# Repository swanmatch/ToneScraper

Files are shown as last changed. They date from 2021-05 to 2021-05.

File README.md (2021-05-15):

# ToneScraper

## 概要

[せきごんさん](https://github.com/sekigon-gonnoc)の[mtch6102評価基板](https://github.com/sekigon-gonnoc/mtch6102_breakout)を参考に、タッチパッドとロータリーエンコーダーを3機搭載した4キーマイクロパッド。

ロータリーエンコーダーは単色の光るエンコーダーかプッシュスイッチ付きのもののどちらか選んで実装できます。

## 部品リスト

| 品目 | 数量 | 備考 |
| :--- | ---: | :--- |
| PCB |  1枚 |  |
| トッププレート |  1枚 |  |
| ボトムプレート |  1枚 |  |
| ProMicro |  1個 |  |
| コンスルー |  2本 |  |
| LED(SK6812mini) |  4個 |  |
| MTCH6102 |  1個 |  |
| レベル変換基板 |  1個 | https://nogikes.booth.pm/items/2008258 |
| 4pinピンヘッダー |  1個 |  |
| ハーフピッチ5pinピンヘッダー |  1個 |  |
| アナログ5mm砲丸LED |  1個 |  |
| 220Ω抵抗 |  1個 |  |
| M2L8丸スペーサ |  4本 |  |
| M2L7六角スペーサ(オスメス) |  6本 |  |
| M2L4ネジ |  8本 |  |
| アングルタクトスイッチ |  1個 |  |
| ゴム足 |  4個 |  |
| KailhChocスイッチ |  4個 |  |
| 1Uキーキャップ |  4個 |  |
| USBケーブル |  1本 |  |
| TRRS JACK |  2個 | パームレスト for SilverbulletRequiemを光らせる場合 |
| TRRSまたはTRSケーブル |  2本 | パームレスト for SilverbulletRequiemを光らせる場合必|
| 圧電サウンダ(PKLCS1212) |  1個 | 圧電サウンダを実装する場合 |
| ダイオード |  1個 | 圧電サウンダを実装する場合 |
| 1KΩ抵抗 | 1個 | 圧電サウンダを実装する場合 |
| 光るロータリーエンコーダー | 3個 | [赤](https://akizukidenshi.com/catalog/g/gP-05762/) [青](https://akizukidenshi.com/catalog/g/gP-05768/) [黄緑](https://akizukidenshi.com/catalog/g/gP-05767/) |
| 100Ω抵抗 |  3個 | 光るロータリーエンコーダーを実装する場合 |
| 通常ロータリーエンコーダー  |  3個 |  |

## 組み立て手順

### LEDの実装

LEDをはんだ付けします。  
欠けている足が右上の三角のシルクに対応します。

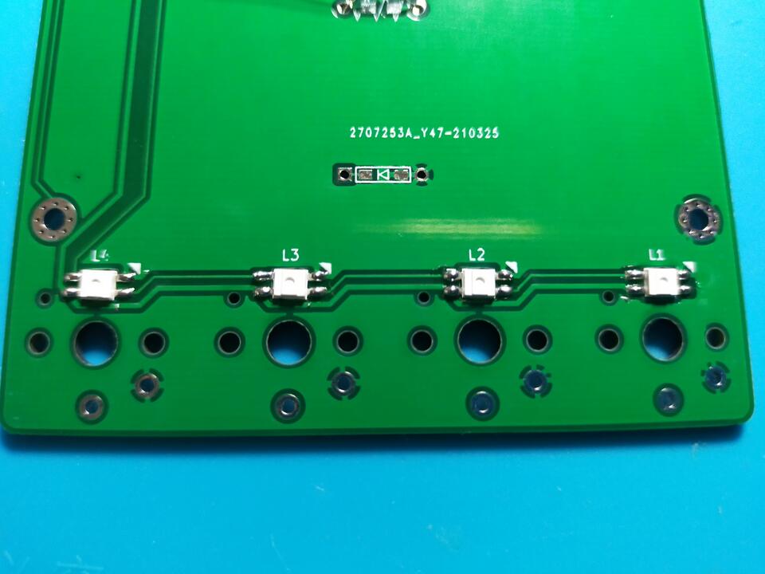
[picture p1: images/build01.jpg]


### アナログLED・抵抗の実装

アナログLEDの横の抵抗とLEDを実はんだ付けします。

LEDは数ミリ浮かせた状態で実装して、トッププレートを付けたときにはみ出るとかっこいいです。

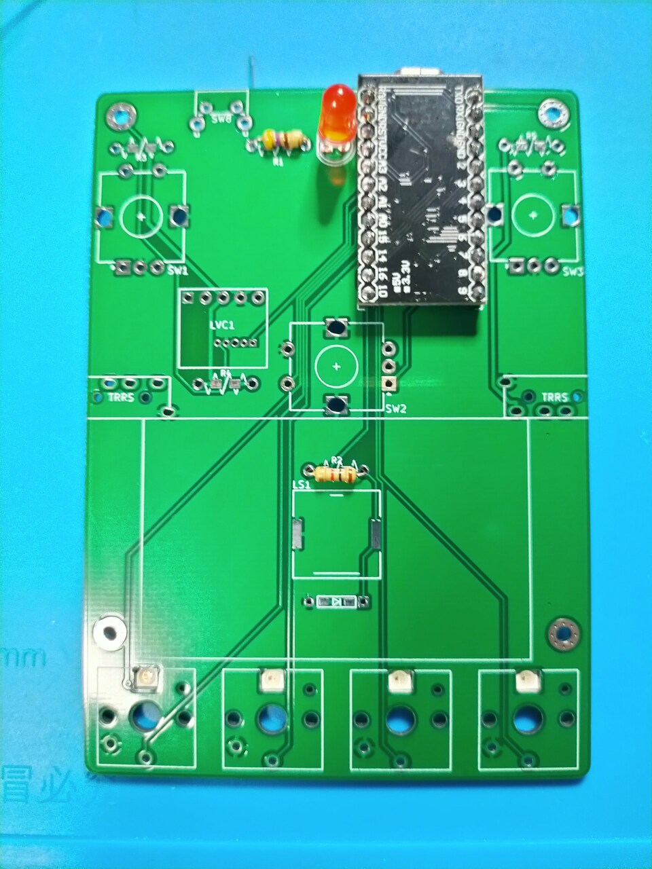
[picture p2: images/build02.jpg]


圧電サウンダを使う場合、ダイオードと1kΩ抵抗、圧電サウンダを、
光るエンコーダーを使う場合、その他の抵抗のフットプリントに100Ω抵抗を実装します。

＊) 圧電サウンダの実装を忘れて写真を撮りました…！

### リセットスイッチ、TRRSジャックの実装

TRRSジャックと、タクトスイッチを実装します。

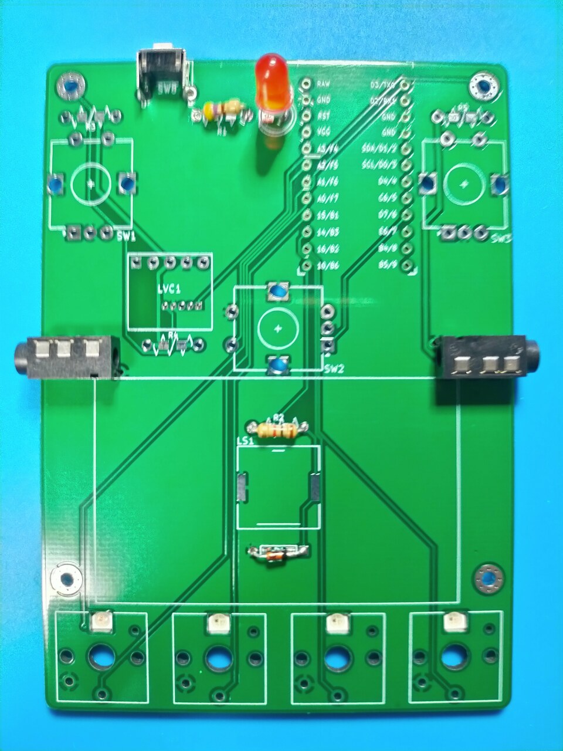
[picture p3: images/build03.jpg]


### レベル変換基板用のピンヘッダの実装

レベル変換基板用のピンヘッダをはんだ付けします。

標準ピッチ基板は表(スイッチ面)から見て一番右側は使っていないので左寄せにします。

ピンヘッダを傾けてはんだ付けしてしまうと変換基板がハマらないので、
変換基板を載せた状態でマスキングテープで固定して、裏からはんだ付けします。

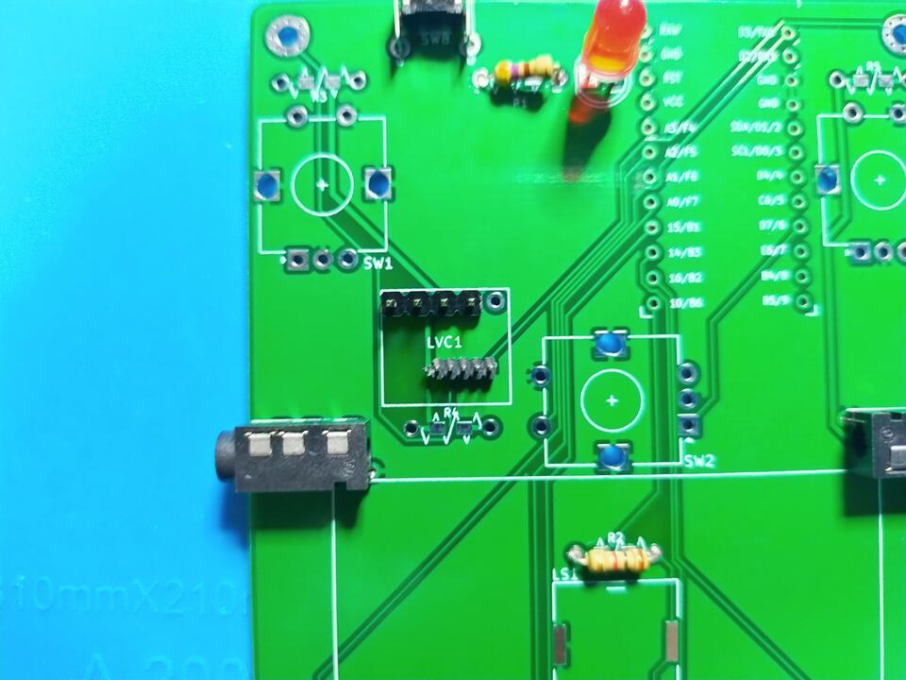
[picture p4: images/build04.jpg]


続いてレベル変換基板をはんだ付けします。

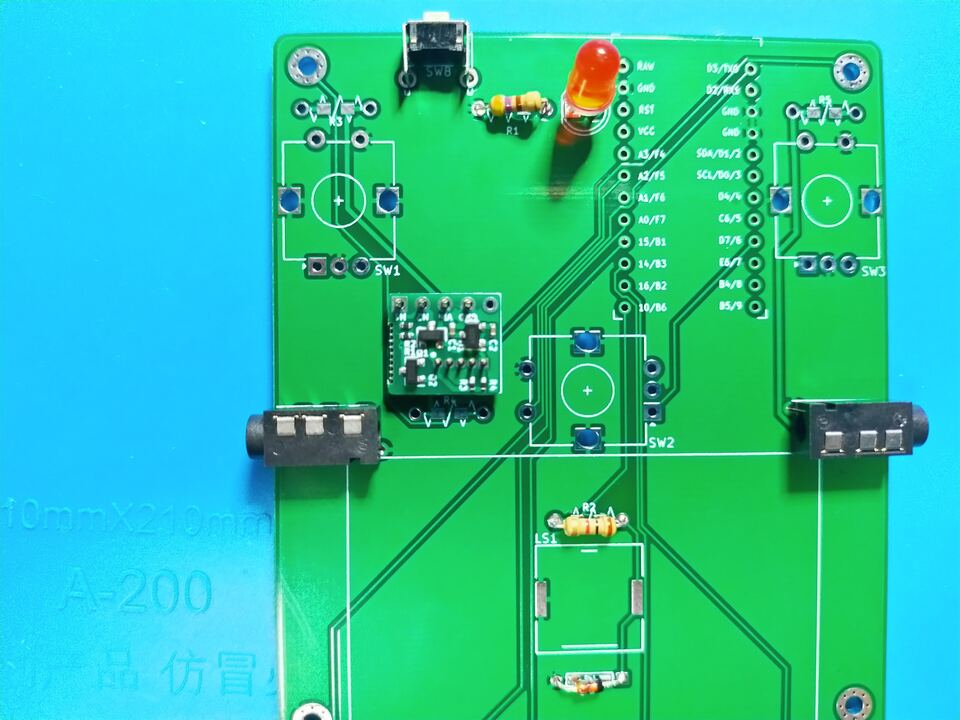
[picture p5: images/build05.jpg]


### Chocスイッチとロータリーエンコーダーの実装

ロータリーエンコーダーとChocスイッチをはんだ付けします。

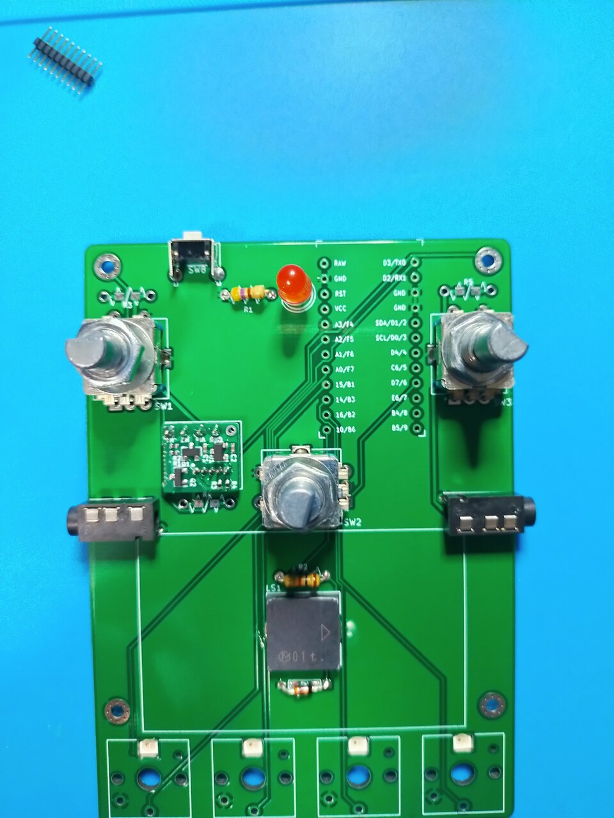
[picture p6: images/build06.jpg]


＊) chocの実装を忘れて写真を撮りました…！

### MTCH6102の実装

MTCH6102をトッププレートに実装します。  
ICに付いている丸い印が右上です。

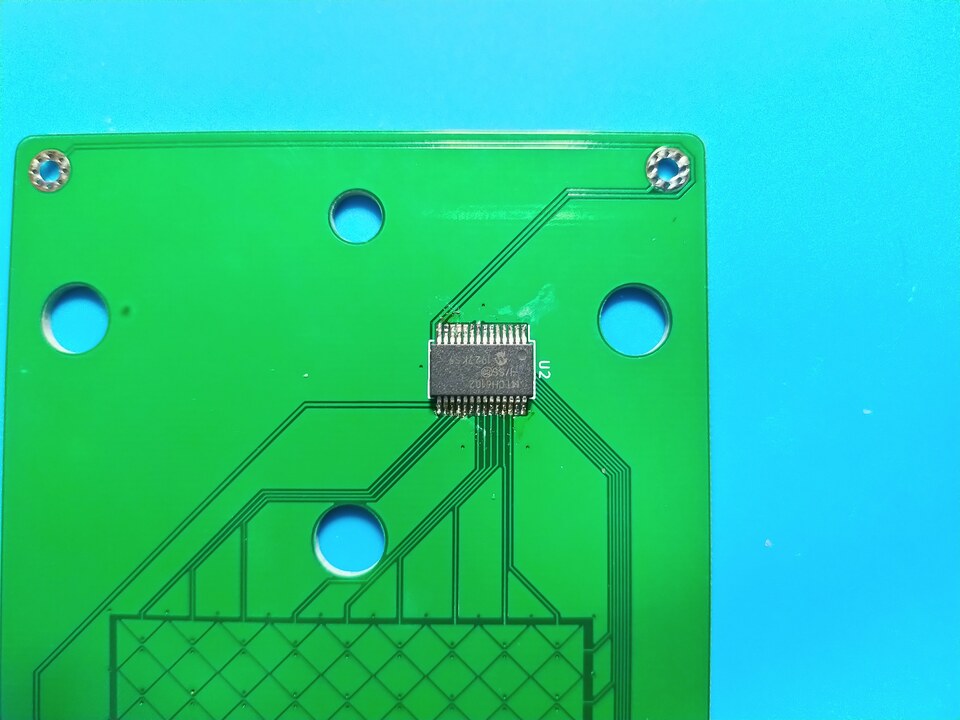
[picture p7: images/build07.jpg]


### スペーサーの実装

スペーサーをはめます。  
上に丸、下に六角です。

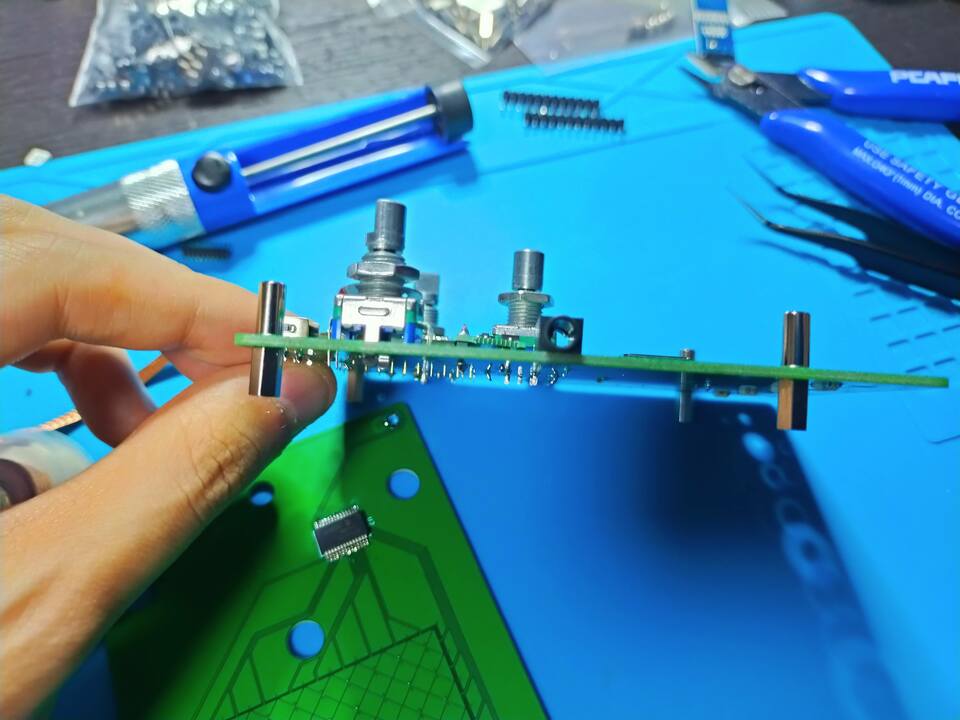
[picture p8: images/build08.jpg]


### ネジ止め

トッププレート、ボトムプレートを挟んでネジ止めします。
ボトムプレートはリバーシブルで使えます。

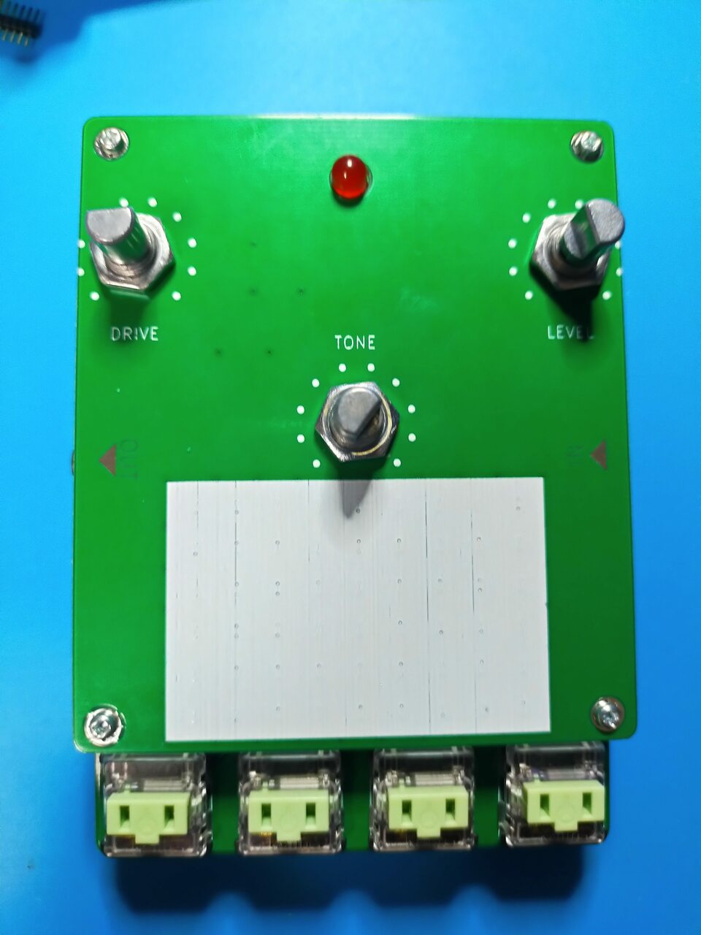
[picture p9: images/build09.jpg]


### キャップ

ロータリーエンコーダー、Chocスイッチのキャップをはめて完成です！

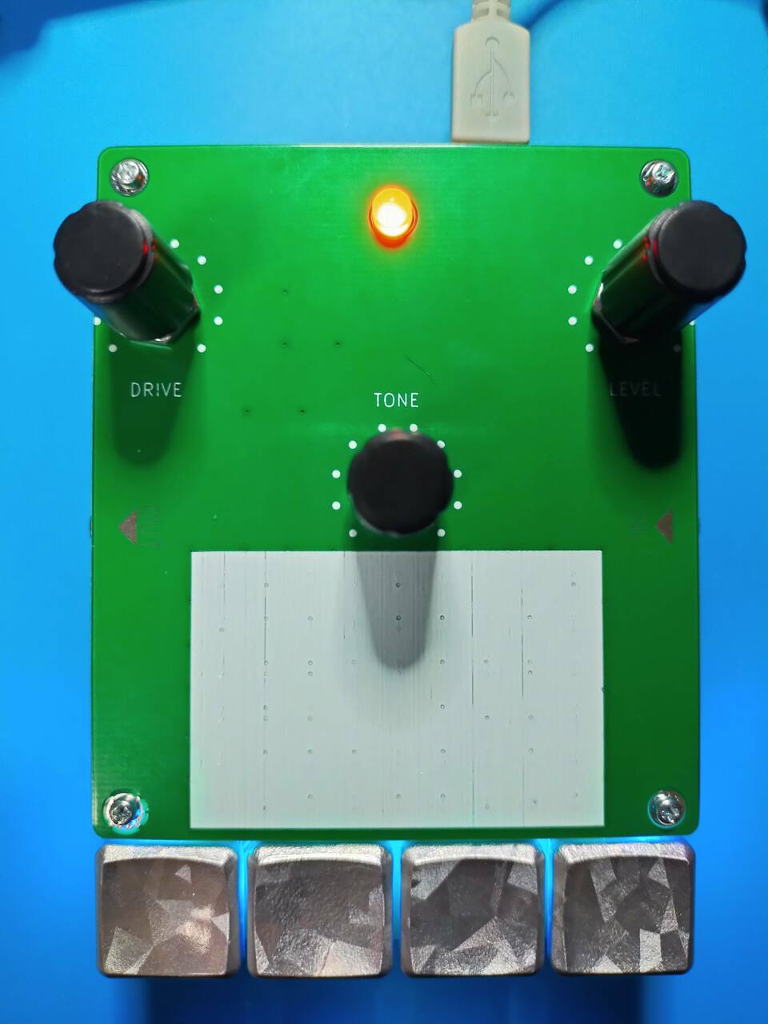
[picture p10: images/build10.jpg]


## ファームウェア

ファームウェアは(ここ)[https://github.com/swanmatch/qmk_firmware/tree/master/keyboards/tone_scraper]に置いてあります。

以下の手順で書き込みます。

QMKの環境構築についてはお使いのOSによって異なりなりますので、
(公式ドキュメント)を読んでください。

```sh
git clone https://github.com/swanmatch/qmk_firmware.git
cd qmk_firmware
make git-submodule
make tone_scraper:default:avrdude
```

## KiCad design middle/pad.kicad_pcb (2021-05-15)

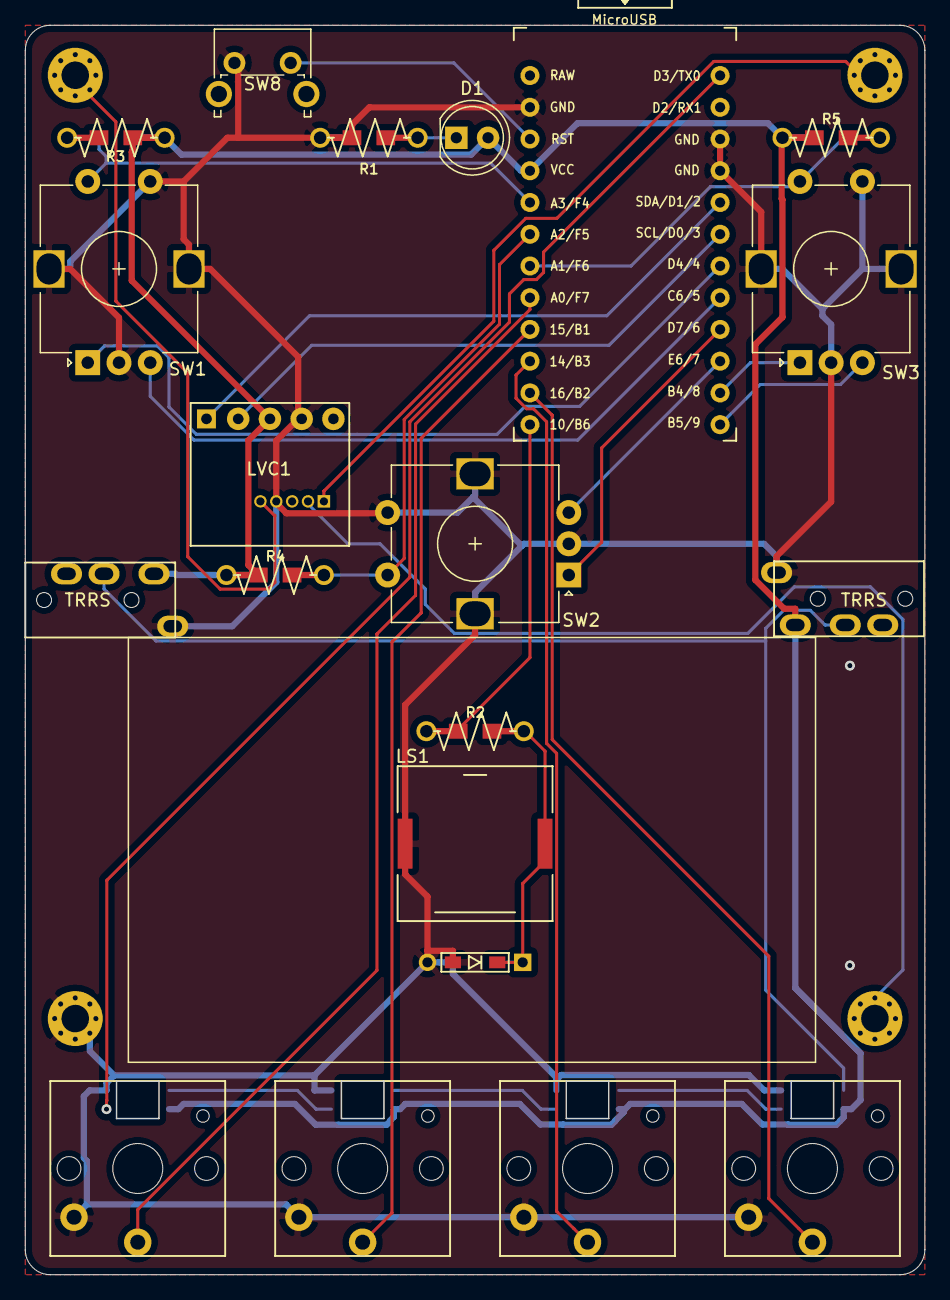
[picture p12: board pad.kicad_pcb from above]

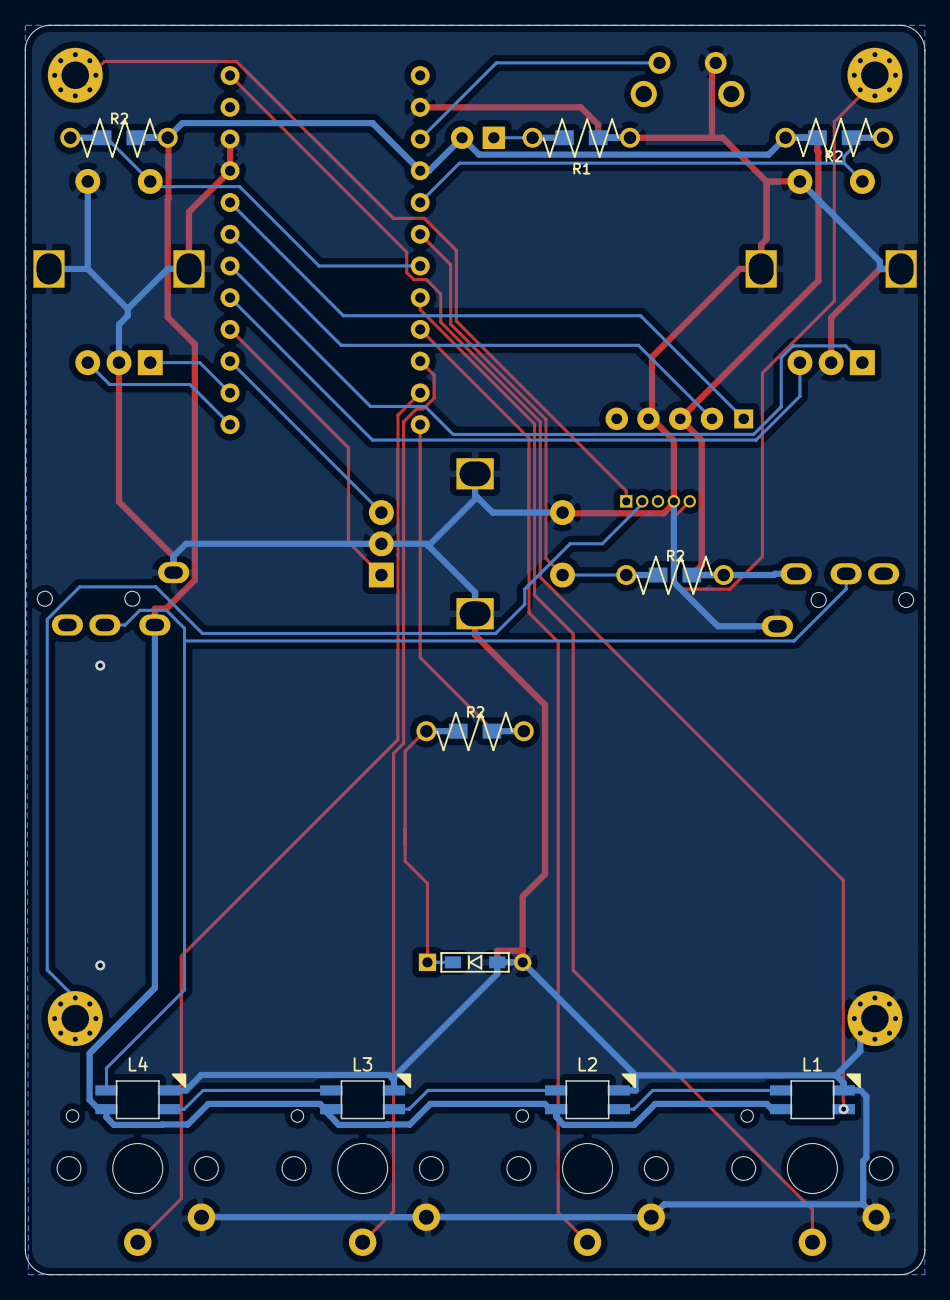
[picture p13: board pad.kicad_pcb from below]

Board: 2 copper layers, 72.0 x 100.0 mm, 28 parts (4 on the bottom side), 29 nets.

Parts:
D1: LED; LED_D5.0mm
D2: 1N4148; D3_TH_SMD
J1, J2: AudioJack4; MJ-4PP-9_1side
J3, J4, J5, J6: Conn_01x01; MountingHole_2.2mm_M2_Pad_Via
L1, L2, L3, L4: YS-SK6812MINI; YS-SK6812MINI-E
LS1: Speaker; PKLCS1212E4001
LVC1: lvc27
R1, R2, R3, R4, R5: R; Resistor-Hybrid
SW1, SW2, SW3: Rotary_Encoder_Switch; RotaryEncoder_Alps_EC12E-Switch_Vertical_H20mm
SW4, SW5, SW6, SW7: SW_PUSH; Choc_1u
SW8: SW_PUSH; SW_Tactile_SPST_Angled_PTS645Vx39-2LFS
U1: ProMicro; ProMicro_v3

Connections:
2.7V: J3.1, LVC1.10
AUDIO: R2.1, U1.13
GND: D2.2, J1.S, J2.S, J6.1, L1.3, L2.3, L3.3, L4.3, LS1.2, LVC1.4, LVC1.9, R1.1, SW1.C, SW1.MP, SW1.S2, SW2.C, SW2.MP, SW2.S2, SW3.C, SW3.MP, SW3.S2, SW4.1, SW5.1, SW6.1, SW7.1, SW8.1, U1.3, U1.4, U1.23
LED: L1.4, U1.1
LEDOUT: J1.R1, J2.R1, L4.2
unnamed: D1.1, R1.2
unnamed: D2.1, LS1.1, R2.2
unnamed: L1.2, L2.4
unnamed: L2.2, L3.4
unnamed: L3.2, L4.4
RE1_A: SW1.A, U1.7
RE1_B: SW1.B, U1.8
RE2_A: SW2.A, U1.9
RE2_B: SW2.B, U1.10
RE3_A: SW3.A, U1.11
RE3_B: SW3.B, U1.12
RESET: SW8.2, U1.22
SCL: LVC1.2, U1.6
SCLK: J5.1, LVC1.6
SDA: LVC1.1, U1.5
SDIO: J4.1, LVC1.7
SW1: R3.2, SW1.S1, U1.20
SW2: R4.2, SW2.S1, U1.19
SW3: R5.2, SW3.S1, U1.18
SW4: SW4.2, U1.17
SW5: SW5.2, U1.16
SW6: SW6.2, U1.15
SW7: SW7.2, U1.14
VCC: D1.2, J1.T, J2.T, L1.1, L2.1, L3.1, L4.1, LVC1.3, R3.1, R4.1, R5.1, U1.21
